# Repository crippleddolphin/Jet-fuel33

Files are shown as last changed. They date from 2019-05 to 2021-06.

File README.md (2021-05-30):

# Jet-fuel33
https://i.imgur.com/FCYjS9T.jpg

# Intro
This is the github page for the Jet Fuel33, a 3x11 ortholinear keyboard that is compatible with alps and mx switches, it also features usb-c.
the layout in this repo is my personal one which is made for use with swerty, although all the files necessary to make your own are available here too.

# Description
My goal with this project was to create the ideal keyboard for me, ever since i got started with the custom keyboard "hobby" i have always been eyeing small keyboards (40% size or smaller). The first custom keyboard i bought was an Orthodox, wich is a 40% split ortholinear ergonomic keyboard. after some consideration i decided that 3x11 would be the optimal layout for me, and since i did not find any existing designs that were 3x11 and used USB-C i decided to design my own keyboard. after teaching myself how to use the pcb design program Kicad i also figured out how to design parts for laser cutting, as that was the method i decided to use for making the case. The original idea was to use a case made out of 5 3mm thick layers of clear acrylic with some standoffs and screws to hold it together. But after making the first prototype i realised that using just 4 layers is possible with some slight modifications to the bottom plate, the modification in question was cutting out a small notch beneath where the usb port is located, otherwise the port gets a bit squished. Making the case have 3mm less room inside which makes it sound slightly better. I have also made one keyboard with a case made out of 3mm thick pieces of high grade birch plywood that were glued together permanently. The use of plywood greatly improves the sound when typing in my opinion.

# Features
- 3x11 ortholinear layout.

- Uses an Atmega32u4 microcontroller.

- Overcurrent, ESD and reverse polarity protection.

- USB Type-C 2.0 port.

- Both MX and Alps compatible.

- QMK powered

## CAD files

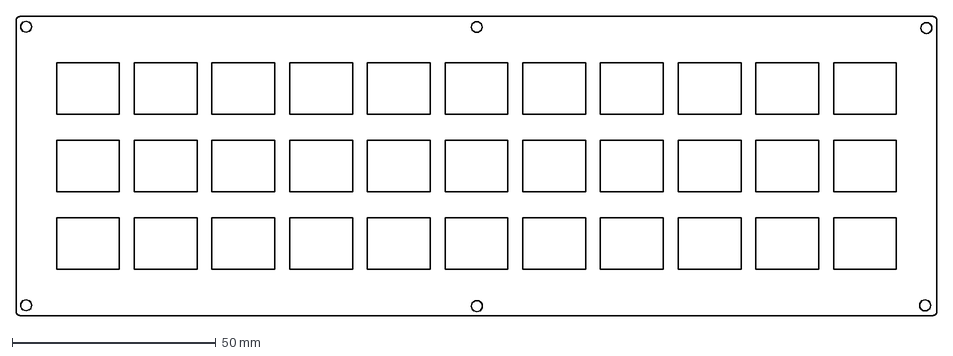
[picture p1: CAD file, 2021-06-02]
case/Alps plate.dxf
225.7 x 73.3 mm

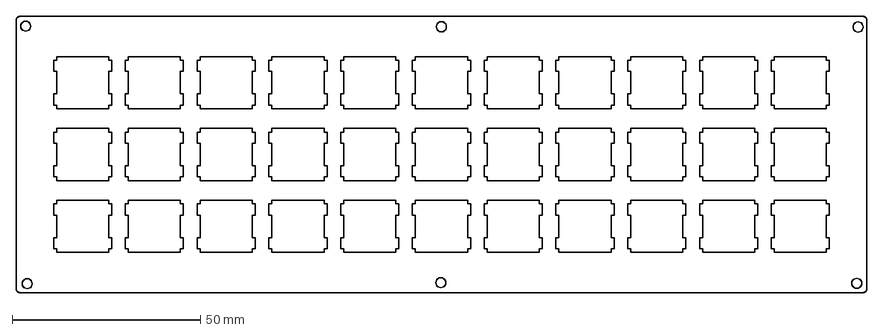
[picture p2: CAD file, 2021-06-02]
case/Mx plate.dxf
225.7 x 73.3 mm

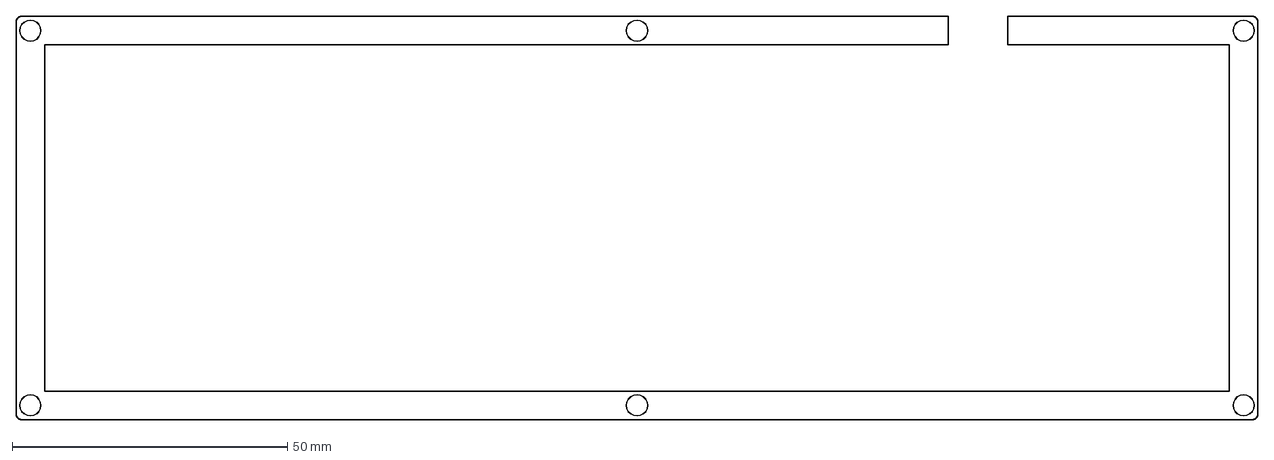
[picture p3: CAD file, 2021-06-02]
case/Middle layer.dxf
225.7 x 73.3 mm

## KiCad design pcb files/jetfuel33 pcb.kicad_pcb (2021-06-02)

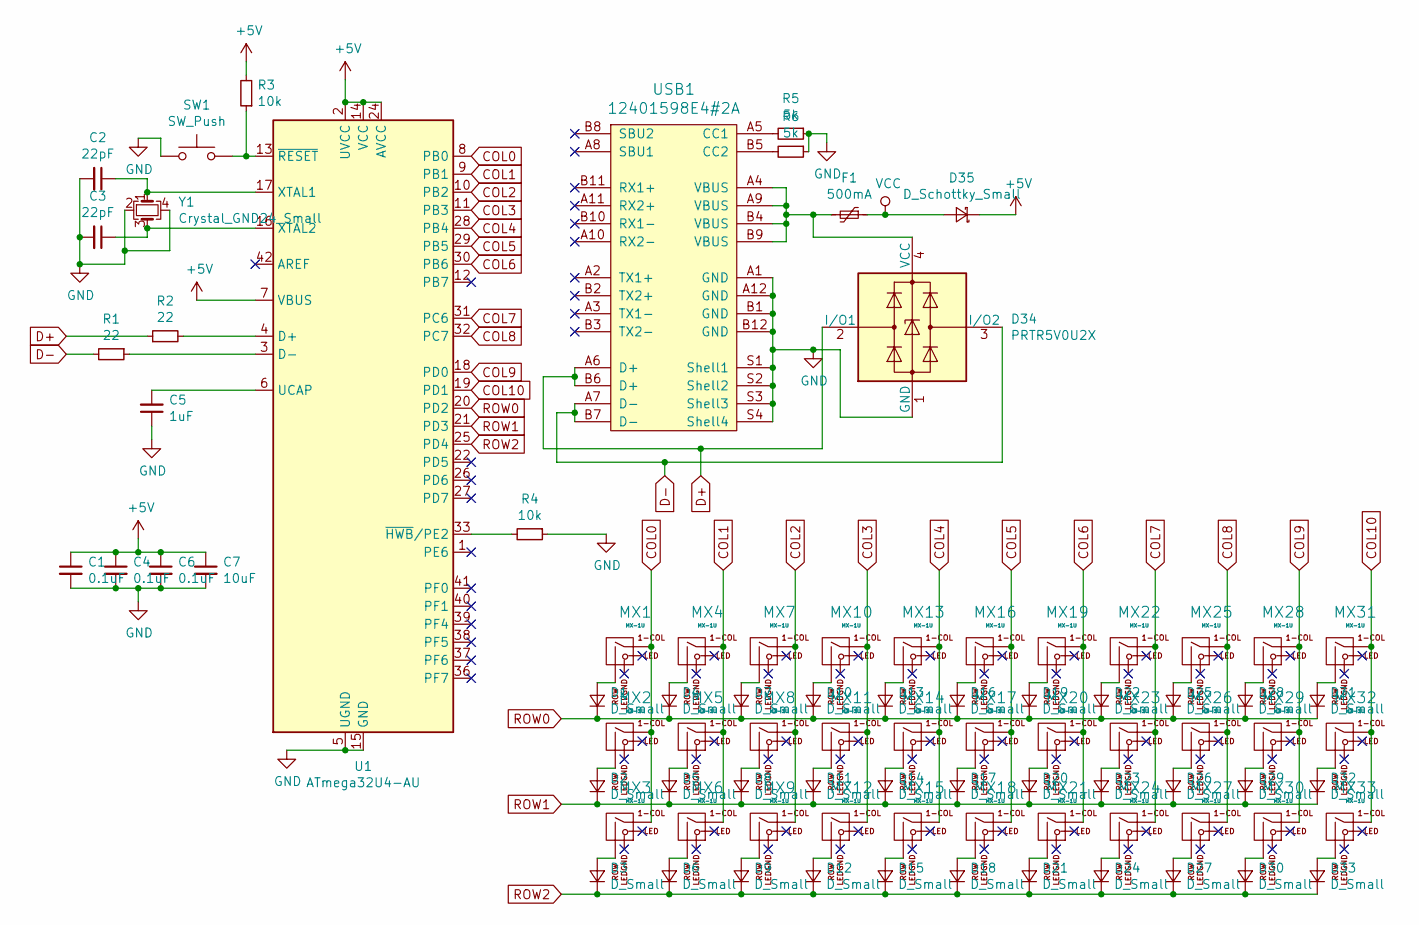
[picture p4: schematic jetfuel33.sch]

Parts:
C1, C4, C6: 0.1uF; C_0805_2012Metric
C2, C3: 22pF; C_0805_2012Metric
C5: 1uF; C_0805_2012Metric
C7: 10uF; C_0805_2012Metric
D1, D2, D3, D4, D5, D6, D7, D8, D9, D10, D11, D12, D13, D14, D15, D16, D17, D18, D19, D20, D21, D22, D23, D24, D25, D26, D27, D28, D29, D30, D31, D32, D33: D_Small; D_SOD-123
D34: PRTR5V0U2X; SOT-143
D35: D_Schottky_Small; D_SOD-123
F1: 500mA; Fuse_1206_3216Metric_Pad1.42x1.75mm_HandSolder
MX1, MX2, MX3, MX4, MX5, MX6, MX7, MX8, MX9, MX10, MX11, MX12, MX13, MX14, MX15, MX16, MX17, MX18, MX19, MX20, MX21, MX22, MX23, MX24, MX25, MX26, MX27, MX28, MX29, MX30, MX31, MX32, MX33: MX-1U; MX-1U-NoLED
R1, R2: 22; R_0805_2012Metric
R3, R4: 10k; R_0805_2012Metric
R5, R6: 5k; R_0805_2012Metric
SW1: SW_Push; SKQG-1155865
U1: ATmega32U4-AU; TQFP-44_10x10mm_P0.8mm
USB1: 12401598E4#2A
Y1: Crystal_GND24_Small; Crystal_SMD_3225-4Pin_3.2x2.5mm

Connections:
+5V: C1.1, C4.1, C6.1, C7.1, D35.1 (K), R3.2, U1.2 (UVCC), U1.7 (VBUS), U1.14 (VCC), U1.24 (AVCC), U1.34 (VCC), U1.44 (AVCC)
COL0: MX1.1 (COL), MX2.1 (COL), MX3.1 (COL), U1.8 (PB0)
COL1: MX4.1 (COL), MX5.1 (COL), MX6.1 (COL), U1.9 (PB1)
COL2: MX7.1 (COL), MX8.1 (COL), MX9.1 (COL), U1.10 (PB2)
COL3: MX10.1 (COL), MX11.1 (COL), MX12.1 (COL), U1.11 (PB3)
COL4: MX13.1 (COL), MX14.1 (COL), MX15.1 (COL), U1.28 (PB4)
COL5: MX16.1 (COL), MX17.1 (COL), MX18.1 (COL), U1.29 (PB5)
COL6: MX19.1 (COL), MX20.1 (COL), MX21.1 (COL), U1.30 (PB6)
COL7: MX22.1 (COL), MX23.1 (COL), MX24.1 (COL), U1.31 (PC6)
COL8: MX25.1 (COL), MX26.1 (COL), MX27.1 (COL), U1.32 (PC7)
COL9: MX28.1 (COL), MX29.1 (COL), MX30.1 (COL), U1.18 (PD0)
COL10: MX31.1 (COL), MX32.1 (COL), MX33.1 (COL), U1.19 (PD1)
D+: D34.2 (I/O1), R2.1, USB1.A6 (D+), USB1.B6 (D+); also elsewhere on the board
D-: D34.3 (I/O2), R1.2, USB1.A7 (D-), USB1.B7 (D-); also elsewhere on the board
GND: C1.2, C2.2, C3.2, C4.2, C5.1, C6.2, C7.2, D34.1 (GND), R4.1, R5.1, R6.1, SW1.1, U1.5 (UGND), U1.15 (GND), U1.23 (GND), U1.35 (GND), U1.43 (GND), USB1.A1 (GND), USB1.A12 (GND), USB1.B1 (GND), USB1.B12 (GND), USB1.S1 (Shell1), USB1.S2 (Shell2), USB1.S3 (Shell3), USB1.S4 (Shell4), Y1.2, Y1.4; also elsewhere on the board
unnamed: C2.1, U1.17 (XTAL1), Y1.1
unnamed: C3.1, U1.16 (XTAL2), Y1.3
unnamed: C5.2, U1.6 (UCAP)
unnamed: D1.2 (A), MX1.2 (ROW)
unnamed: D2.2 (A), MX2.2 (ROW)
unnamed: D3.2 (A), MX3.2 (ROW)
unnamed: D4.2 (A), MX4.2 (ROW)
unnamed: D5.2 (A), MX5.2 (ROW)
unnamed: D6.2 (A), MX6.2 (ROW)
unnamed: D7.2 (A), MX7.2 (ROW)
unnamed: D8.2 (A), MX8.2 (ROW)
unnamed: D9.2 (A), MX9.2 (ROW)
unnamed: D10.2 (A), MX10.2 (ROW)
unnamed: D11.2 (A), MX11.2 (ROW)
unnamed: D12.2 (A), MX12.2 (ROW)
unnamed: D13.2 (A), MX13.2 (ROW)
unnamed: D14.2 (A), MX14.2 (ROW)
unnamed: D15.2 (A), MX15.2 (ROW)
unnamed: D16.2 (A), MX16.2 (ROW)
unnamed: D17.2 (A), MX17.2 (ROW)
unnamed: D18.2 (A), MX18.2 (ROW)
unnamed: D19.2 (A), MX19.2 (ROW)
unnamed: D20.2 (A), MX20.2 (ROW)
unnamed: D21.2 (A), MX21.2 (ROW)
unnamed: D22.2 (A), MX22.2 (ROW)
unnamed: D23.2 (A), MX23.2 (ROW)
unnamed: D24.2 (A), MX24.2 (ROW)
unnamed: D25.2 (A), MX25.2 (ROW)
unnamed: D26.2 (A), MX26.2 (ROW)
unnamed: D27.2 (A), MX27.2 (ROW)
unnamed: D28.2 (A), MX28.2 (ROW)
unnamed: D29.2 (A), MX29.2 (ROW)
unnamed: D30.2 (A), MX30.2 (ROW)
unnamed: D31.2 (A), MX31.2 (ROW)
unnamed: D32.2 (A), MX32.2 (ROW)
unnamed: D33.2 (A), MX33.2 (ROW)
unnamed 51: D34.4 (VCC), F1.2, USB1.A4 (VBUS), USB1.A9 (VBUS), USB1.B4 (VBUS), USB1.B9 (VBUS); also elsewhere on the board
unnamed: R1.1, U1.3 (D-)
unnamed: R2.2, U1.4 (D+)
unnamed: R3.1, SW1.2, U1.13 (~RESET)
unnamed: R4.2, U1.33 (~HWB~/PE2)
unnamed 56: R5.2, USB1.A5 (CC1); also elsewhere on the board
unnamed 57: R6.2, USB1.B5 (CC2); also elsewhere on the board
ROW0: D1.1 (K), D4.1 (K), D7.1 (K), D10.1 (K), D13.1 (K), D16.1 (K), D19.1 (K), D22.1 (K), D25.1 (K), D28.1 (K), D31.1 (K), U1.20 (PD2)
ROW1: D2.1 (K), D5.1 (K), D8.1 (K), D11.1 (K), D14.1 (K), D17.1 (K), D20.1 (K), D23.1 (K), D26.1 (K), D29.1 (K), D32.1 (K), U1.21 (PD3)
ROW2: D3.1 (K), D6.1 (K), D9.1 (K), D12.1 (K), D15.1 (K), D18.1 (K), D21.1 (K), D24.1 (K), D27.1 (K), D30.1 (K), D33.1 (K), U1.25 (PD4)
VCC: D35.2 (A), F1.1

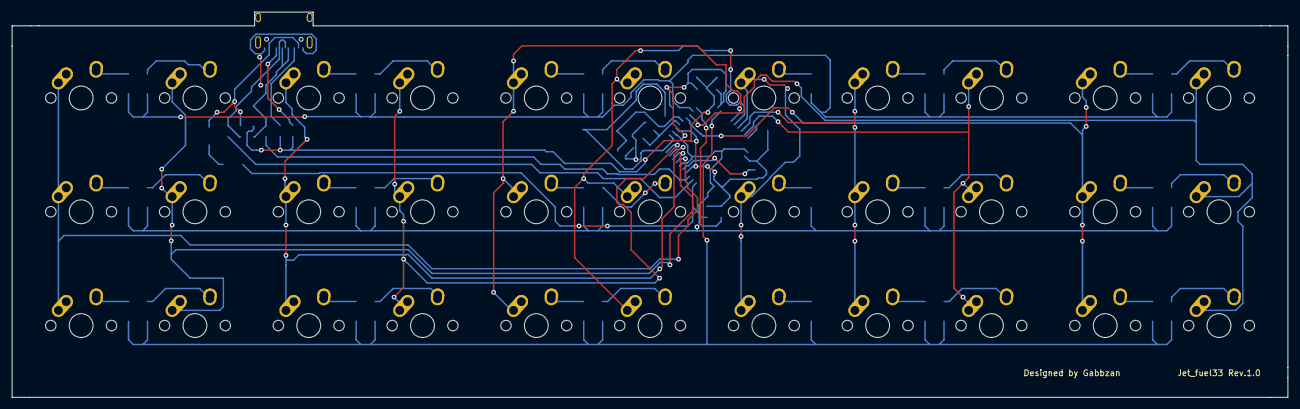
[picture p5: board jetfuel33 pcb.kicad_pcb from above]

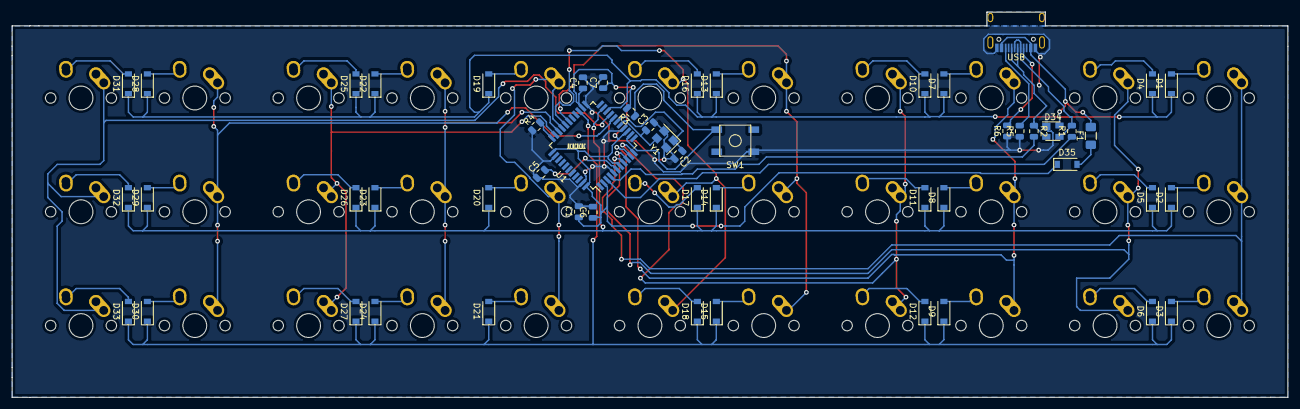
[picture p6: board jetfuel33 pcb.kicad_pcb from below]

Board: 2 copper layers, 213.6 x 64.5 mm, 86 parts (53 on the bottom side), 62 nets.

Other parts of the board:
USB: HRO-TYPE-C-31-M-12

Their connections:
D+: USB.6, USB.8; also elsewhere on the board
D-: USB.5, USB.7; also elsewhere on the board
GND: USB.1, USB.12; also elsewhere on the board
unnamed 51: USB.2, USB.11; also elsewhere on the board
unnamed 56: USB.10; also elsewhere on the board
unnamed 57: USB.4; also elsewhere on the board

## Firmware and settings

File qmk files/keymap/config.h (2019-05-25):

#ifndef CONFIG_H
#define CONFIG_H

#include "config_common.h"

/* USB Device descriptor parameter */
#define VENDOR_ID       0xFEED
#define PRODUCT_ID      0x6060
#define DEVICE_VER      0x0001
#define MANUFACTURER    qmkbuilder
#define PRODUCT         keyboard
#define DESCRIPTION     Keyboard

/* key matrix size */
#define MATRIX_ROWS 3
#define MATRIX_COLS 11

/* key matrix pins */
#define MATRIX_ROW_PINS { D2, D3, D4 }
#define MATRIX_COL_PINS { B0, B1, B2, B3, B4, B5, B6, C6, C7, D0, D1 }
#define UNUSED_PINS

/* COL2ROW or ROW2COL */
#define DIODE_DIRECTION COL2ROW

/* number of backlight levels */

#ifdef BACKLIGHT_PIN
#define BACKLIGHT_LEVELS 3
#endif

/* Set 0 if debouncing isn't needed */
#define DEBOUNCING_DELAY 5

/* Mechanical locking support. Use KC_LCAP, KC_LNUM or KC_LSCR instead in keymap */
#define LOCKING_SUPPORT_ENABLE

/* Locking resynchronize hack */
#define LOCKING_RESYNC_ENABLE

/* key combination for command */
#define IS_COMMAND() ( \
    keyboard_report->mods == (MOD_BIT(KC_LSHIFT) | MOD_BIT(KC_RSHIFT)) \
)

/* prevent stuck modifiers */
#define PREVENT_STUCK_MODIFIERS


#ifdef RGB_DI_PIN
#define RGBLIGHT_ANIMATIONS
#define RGBLED_NUM 0
#define RGBLIGHT_HUE_STEP 8
#define RGBLIGHT_SAT_STEP 8
#define RGBLIGHT_VAL_STEP 8
#endif

#endif
